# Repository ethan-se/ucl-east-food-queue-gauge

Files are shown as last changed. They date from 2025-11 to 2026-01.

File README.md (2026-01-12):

# Gauge & Grab

## Project Authors

This project was collaboratively developed by:

Ethan Taylor

Madina Diallo

Yussr Osman Kamil Bashir

🔗 GitHub Repository

The full source code, documentation, and project assets are available at:

👉 https://github.com/ethan-se/ucl-east-food-queue-gauge

## 📄 About This Repository
This repository contains the code, documentation, and supporting materials for the UCL East Food Queue Gauge project, developed as part of an academic group assignment.

**A Physical-[Digital](https://youtube.com/shorts/w2yIuAzpJI0?si=osPyPwr-uZf5rIN4) IoT System for Campus Dining Decisions**

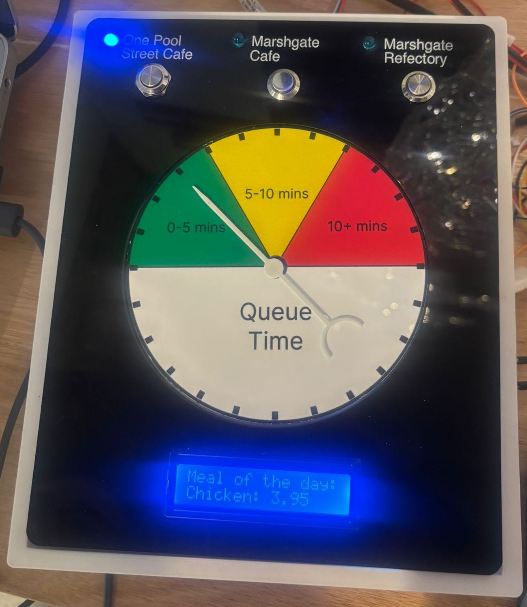
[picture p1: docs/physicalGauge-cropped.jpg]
Picture of Gauge and Grab physical device


---
## 1. Introduction & Rationale

University campus users frequently face uncertainty when deciding where to eat, particularly during peak hours. At UCL East, dining locations such as Pool Street Café, Marshgate Café, and Marshgate Canteen offer varied menus, daily specials, prices, and service speeds. However, users currently lack a quick, data-driven way to compare queue lengths and menu value in real time. This often leads to inefficiencies, long queues, and dissatisfaction.

Gauge & Grab was developed to address this everyday decision-making challenge through the design of a physical data device paired with a digital twin interface. The project explores how live (simulated) data, delivered through an Internet of Things (IoT) pipeline, can be visualised both analogue-physically and digitally augmented to support rapid, informed choices.

(Letsa, 2017)

The system allows users to instantly view:
- Estimated queue waiting time
- Daily specials and prices (Monday–Friday)
- Location-specific service characteristics

**Research Question:**  
*How can food-service data be presented in a fast, simple, and meaningful way to support informed decision-making on campus?*

---

## 2. Project Aims & Group Objectives

As a group, our objectives were to:
- Design and prototype a physical gauge that visualises live queue time immediately.
- Develop a digital twin and dashboard (Unity-based) that responds to the same live data feed.
- Use MQTT to demonstrate a real-time, end-to-end data pipeline.
- Enable users to make a dining decision within 5 seconds of interacting with the device.
- Show how analogue and digital systems can work together in a smart campus context.

---

## 3. Physical Device Design

### a. Aesthetic & Interaction Design

The physical gauge was designed to integrate naturally into the built environment at UCL East. Its form factor was inspired by devices commonly found near lecture rooms, such as thermostats or card readers, encouraging intuitive, brief interactions upon entering or exiting a space. 

(Aman, 2025)

The enclosure features:
- A laser-cut black acrylic front panel
- White etched typography using Helvetica, chosen for legibility and familiarity (Osborn, 2012)
- Magnetic mounting inspired by prior Connected Environments projects (e.g. SubRadar) (Low et al., 2024)
- A minimalist black-and-white aesthetic to complement existing campus infrastructure.
  


Each dining location is represented by:
- A dedicated button
- A corresponding LED indicator
- Clear etched labels on the front panel
  
  

This allows users to switch between locations with a single press, immediately updating the data displayed.

### b. Dial Graphic & Queue Representation

Queue time is visualised through a servo-driven pointer rotating across a semi-circular dial. The dial uses colour-coded zones:
- **Green (0–5 min)** – acceptable wait
- **Yellow (5–10 min)** – situational
- **Red (10+ min)** – undesirable

The dial graphic was designed in Figma and UV-printed onto acrylic. Due to manufacturing constraints, the final markers represent 75-second increments rather than the intended 60 seconds, an acknowledged limitation retained due to time constraints.



### c. Build Challenges

During final assembly, several physical issues emerged:
- The acrylic dial height exceeded the available servo shaft length.
- A 3D-printed spacer reduced torque accuracy.
- The final demonstration used a paper prototype dial to ensure functional clarity.

These challenges highlighted the importance of earlier physical prototyping and mechanical testing, particularly when combining laser-cut and 3D-printed components.

---

## 4. Code & Device Logic

### a. Arduino / NodeMCU Basis

The embedded code was built upon example implementations from the Open Gauges Project, retaining core libraries for:
- Wi-Fi connectivity
- MQTT publish/subscribe.
- Servo motor control

(Hudson-Smith, 2025)

Additional libraries were introduced to support:
- LCD screen output
- JSON parsing via Arduino Json



### b. MQTT Topic Switching

A key extension beyond the example code was dynamic topic switching, allowing one device to subscribe to three different MQTT topics, one per dining location.

An array of topics is stored, and button presses trigger:
- Unsubscription from the current topic
- Index update
- Subscription to the selected topic

This enables direct selection rather than cycling, improving usability and responsiveness.

### c. JSON Parsing & Data Handling

Incoming MQTT messages are structured as JSON objects. The device extracts:

**queue time** → mapped to servo position.

Due to time limitations, LCD display of daily specials and prices was not fully implemented in the final build, though code scaffolding demonstrates how this would be achieved safely within LCD character limits.

Queue values are constrained to a maximum range to prevent the servo exceeding the physical limits of the dial.



---

## 5. Data Design & Live MQTT System

### a. Research-Informed Dataset Design

Rather than using arbitrary values, we grounded our dataset in on-site observations and staff conversations at:
- Pool Street Café
- Marshgate Café
- Marshgate Canteen

Staff were asked about:
- Busy periods
- Average service speed
- Queue behaviour
- Menu rotation and daily specials

These insights informed our assumptions and data structure.



### b. Queue Time Model

Queue time was calculated using a simplified but transparent formula:

```
queue time = people_in_queue × service factor
```

Service factors differed by location based on observed service speed:
- **Pool Street Café**: ×1
- **Marshgate Café**: ×2
- **Marshgate Canteen**: ×3

This approach prioritised clarity and reproducibility over realism, appropriate for a demonstrative prototype.

(Eclipse Mosquitto, 2025)  
(Eclipse Foundation, 2024)



### c. MQTT Architecture

Data is published using the following topic hierarchy:



```
student/CASA0019/gauge&grab/
   ├── pool_street
   ├── marshgate_cafe
   └── marshgate_canteen
```

Each message includes:
- Location
- People in queue
- Queue time
- Daily special
- Price

Data is generated every 2 seconds via a Python script using Dabo-style publishing, simulating a live operational system.



### d. Verification

The pipeline was validated using MQTT Explorer, confirming:
- Correct topic structure
- Live updates across all locations
- Data consistency between publisher, physical device, and digital twin

(Python Software Foundation, 2025)  
(Schiffler, 2025)

### e. Data Summary

```
Real Questions at Cafés
        ↓
Draft dataset (menus, multipliers, queue ranges)
        ↓
Python generator → Live values every 2 seconds
        ↓
MQTT Publish → student/CASA0019/gauge&grab/<location>
        ↓
Physical Gauge Reads (Arduino)
        ↓
Digital Twin Reads (Unity AR)
```

---

## 6. Digital Twin (Unity)



## a.	Purpose of the Digital Twin

The digital twin complements our physical gauge by using augmented reality to visualise our dataset into an interactive digital gauge and dashboards for each location. The AR gauge receives live data from MQTT enabling users to pick their chosen location and view queue times and specials efficiently without having to be in proximity to the physical gauge. To ensure the user would be able to view the gauge in AR, the gauge was turned into a prefab in unity to ensure better control of the 3D model. In the scene with the XR Origin game object selected the tap to place script is added as a component in the inspector window with the digital gauge prefab selected as the game object to instantiate (workshop 6 Cetools.org, 2026). It is vital that the AR object (the digital gauge prefab) only lives inside the tap to place component and not as a game object in the scene hierarchy. An AR object UI bridge script is added as a component to the AR object prefab to enable the button to allow users to transition from the prefab to the dashboard.



The Dashboard expands on the gauge by turning historical and live data into digestible charts and tables that allow users to better plan and understand their canteen options (Workshop 3 Cetools.org, 2026). The dashboard exists as a child of the AR object. Each location's dashboard includes:
- Location name 
- A table that outlines the daily food specials for the week with a description of the food item, its price, caloric value, allergens, as well as an estimated serving time. This is incorporated in the dashboard in an image of each table. 
- A line graph that represents the locations weekly peak wait time. The graph enables users to plan and better understand wait time trends for the week. 
- Buttons were used to allow user to cycle from the AR object to the dashboard, A further three buttons were added to allow users to switch dashboards and return to the gauge. A dashboard navigation script ensures that buttons work smoothly and allow users switch between the dashboards.



### b. Unity & MQTT Integration

Our digital twin system transforms data received from MQTT into interactive and dynamic representations through our digital gauge and dashboards. An MQTT manager game object with an MQTT manager script as a component is added to the scene. The MQTT manager receives messages from MQTT ensuring connection the MQTT broker and subscription to our topics. The transformation of MQTT data into our interactive representations is done through two MQTT controller scripts.



For the digital gauge, an MQTT controller script was attached as a component of our AR object. This script locates the MQTT manager in the scene and receives data from its subscribed topics (workshop 6 Cetools.org, 2026). The MQTT controller script ensures that the gauge only displays data from the user's chosen location and ignores messages related to the other locations. Further the script changes the messages which it receives as Json text into C# strings and integers. The queue time is then calculated in the script as well as ensuring that the queue time displayed works with our gauge's range of rotation, start and end values, and gauge needles rotation.



As the dashboard exists as a child of the AR object the MQTT WeeklyChart Controller dashboard controller script is placed as a component inside the dashboard. The dashboard controller script receives data from the same MQTT manager however this script composites the data received over time to allow for it to be analysed. The controller tracks the busiest times for each location and visualises via a line chart for each location that displays weekly peak times.



### c. Limitations During Presentation

An issue faced was late integration of live data which was only successfully implemented the day of the presentation. This hindered our ability to assess whether the data was displayed and initialised correctly on the digital gauge and the line charts in the dashboard. This was further impacted as we faced issues with tap to place during the presentation that prevented the AR object from displaying as well as the button required to display the dashboard. 

We will ensure that issues like these are mitigated in the future by ensuring earlier end-to-end testing and ensuring that we document and film the tap to place function working prior to implementing the dashboard to ensure that a working demo was available for the presentation.

---

## 7. Individual Contributions

**Ethan Taylor**: Led physical device design, enclosure fabrication, dial graphics, servo integration, and Arduino logic.

**Madina Diallo**: Led project coordination, dataset design, MQTT architecture, Python data generation, system pipeline integration, documentation. 

**Yussr Osman Kamil Bashir**: Supported research, data structuring, testing, Unity dashboard development, and system validation.

---

## 8. Reflection

### a. What Worked Well
- Clear end-to-end data pipeline
- Shared MQTT feed driving physical + digital outputs.
- Intuitive, glanceable physical interface
- Strong alignment between research, data, and design

### b. Challenges and Limitations
- Simulated (dummy) data only.
- Simplified queue model
- Late physical and AR testing
- Mechanical constraints in final build

These were accepted to prioritise system architecture and real-time interaction.

---

## 9. Future Work

Future iterations could include:

- Address the 16-character LCD limitation by replacing it with a graphical OLED/TFT display or by using symbolic, colour-based indicators (e.g. LED bars or rings) to convey queue intensity. 

- A future improvement could also allow users to submit short, optional feedback digitally, and via an AR-based digital button after visiting a café, enabling us to compare lived experience with system estimates and continuously improve queue-time accuracy.

- Real queue detection via sensors or computer vision

- Integration with POS or menu management systems

- Predictive queue modelling using historical data.

- Personalisation (dietary needs, budget filters)

- Mobile companion app

- Staff-facing operational dashboard

Such developments would transform Gauge & Grab into a deployable smart-campus service (Letsa, 2017).

---

## 10. Conclusion

Gauge & Grab demonstrates how research-informed data, live MQTT messaging, and physical-digital visualisation can be combined into a coherent IoT system. 

We transformed simple café research, queue observations, menu requests, and staff Q&A into a structured dataset. We automated it with Python, broadcast it live through MQTT, and then connected both a physical gauge and an AR digital twin to the same data stream. This created a complete end-to-end IoT system built from real research, simulated data, and live messaging.

---

## References

- Aman, A. (2025) *Hand adjusting a smart thermostat on a white wall*. Vecteezy. Available at: https://www.vecteezy.com/photo/71521679-hand-adjusting-a-smart-thermostat-on-a-white-wall-increasing-the-room-temperature-for-comfort-and-energy-efficiency-the-digit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

- Cetools.org (2026a) *03: Dashboard and Real Time Data*. Available at: https://workshops.cetools.org/codelabs/casa0019-03-unity-dashboard/index.html

- Cetools.org (2026b) *06: Unity AR Physical to Digital*. Available at: https://workshops.cetools.org/codelabs/casa0019-06-unity-ar-pd/index.html

- Eclipse Foundation (2024) *paho.mqtt.python: Eclipse Paho MQTT Python client library*. Available at: https://github.com/eclipse-paho/paho.mqtt.python

- Eclipse Mosquitto (2025) *MQTT: Lightweight messaging protocol*. Available at: https://mosquitto.org/

- Hudson-Smith, A. (2025) *WindSpeedGauge.ino*. Open-Gauges. Available at: https://github.com/ucl-casa-ce/Open-Gauges/blob/main/Arduino/WindSpeedGauge/WindSpeedGauge.ino

- Letsa, L. (2017) 'Assessing the Effect of Waiting Times on Restaurant Service Delivery in the Ho Municipality, Ghana', *European Business & Management*, 3(6), p. 113. https://doi.org/10.11648/j.ebm.20170306.13

- Low, E. et al. (2024) *CASA0019: Sensor Data Visualisation – SubRadar*. Available at: https://github.com/rorschachwilpeng/casa0019/

- Osborn, J.R. (2012) 'Helvetica and the New York City Subway System', *Design and Culture*, 4(1), pp. 120–122. https://doi.org/10.2752/175470812X13176523285796

- Python Software Foundation (2025) *Python documentation*. Available at: https://www.python.org/doc/

- Schiffler, A. (2025) *How to use the Paho MQTT client in Python*. Cedalo Blog. Available at: https://cedalo.com/blog/configuring-paho-mqtt-python-client-with-examples/

- UCL Centre for Advanced Spatial Analysis (2025) *DaBo: Data in a Box repository*. Available at: https://github.com/ucl-casa-ce/dabo

---

## Acknowledgement

This report would like to acknowledge that AI was used to assist with support for coding in our project. AI was used to assist with coding for our physical gauge, digital twin, and data. AI was used in line with UCL assessment guidelines and was not used to generate ideas or text.

---

## License

This project was developed as part of CASA0019: Sensor Data Visualisation at UCL Centre for Advanced Spatial Analysis.

---

*For questions or collaboration opportunities, please contact the project team through the UCL CASA Connected Environments programme.*

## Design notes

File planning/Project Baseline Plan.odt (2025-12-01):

Project Baseline Plan

10-Day Product Development Timeline: Gauge & Grab System

Our Gauge & Grab System helps UCL East users pick the smartest meal option by instantly showing which location offers the fastest service and most appealing menu through a physical colour-coded gauge and a digital twin rich in contextual data.

🟢 Physical Gauge
🔵 Digital Twin
🟣 GitHub & Report

This timeline assumes the 10-day work period runs from Day 1 (December 2nd) to Day 10 (December 11th), with the final Showcase on December 12th.

Day | Date (Approx.) | Phase / Milestone | Key Tasks (Breakdown) | Assigned Team Lead | Necessary Tools/Systems
1 | Dec 2nd | Concept & Architecture (M1: System Spec Approved) | 1. Define final scope of 3 dining locations (Pool, Marshgate Cafe, Canteen). 2. Finalise Data Model Schema (EWT, Stock, Score, Weather). 3. Physical: Select Microcontroller (e.g., ESP32/Arduino) and components (stepper motor for needle, small TFT/E-Ink screen). 4. Digital: Choose Tech Stack (React/Next.js for Twin, Firebase/Firestore for Database). | MD (Data Lead) | Miro/Figma, Google Sheets, Arduino IDE, Visual Studio Code, Git/GitHub.
2 | Dec 3rd | Design & Mockups (M2: High-Fidelity Mockups Complete) | 1. Physical: Design 3D model for gauge housing (incorporate needle, screen, 3 buttons, colour zones). 2. Digital: Create high-fidelity UI/UX mockups for Digital Twin (Attractiveness Chart, Maps, Dialogue). 3. Data: Build EWT simulation logic (based on time of day, events, etc.) and create mock JSON feed. | ET (Design Lead) | Figma/Sketch, Fusion 360/Tinkercad, Python (for EWT simulation script).
3 | Dec 4th | Hardware Development I (M3: Core Physical Components Wired) | 1.Physical: 3D print initial casing prototype. 2. Physical: Wire and test microcontroller (MCU) with Wi-Fi/Cloud connection. 3. Integrate Stepper Motor control for Needle movement (0 to 180 degrees mapping EWT). | YOKB (Hardware Lead) | Arduino IDE/PlatformIO, Breadboard, Stepper Motor (with driver), Wires, 3D Printer (e.g., UCL workshop).
4 | Dec 5th | Data Pipeline Setup (M4: Data Mocking & DB Connection Ready) | 1. Data: Set up Firestore database (collections for locations, menu_items, EWT_history, weather). 2. Data: Write API endpoint (Node.js/Python) to serve mock EWT/Stock/Score data. 3. Physical: MCU pulls data from the API and successfully prints raw data to the Serial Monitor. | MD (Data Lead) | Firebase/Firestore, Node.js/Python, Postman (API Testing).
5 | Dec 6th | Digital Twin Development I (M5: Core Digital Twin UI Functional) | 1. Digital: Set up the main web application framework (React/Next.js) and GitHub Pages deployment environment. 2. Develop the main Dashboard layout, including placeholders for all 3 locations. 3. Integrate Chart.js/Recharts for Menu Attractiveness Chart (hardcoded data initially). | ET (Design Lead) | React/Tailwind CSS, VS Code, Git/GitHub.
6 | Dec 7th | Physical Integration I & Twin Data (M6: Physical Gauge EWT Live) | 1. Physical: Implement E-Ink/LED display showing the 'top item' status. 2. Physical: Map EWT values (from live data feed) to the Needle position (0-5 min Green, 5-10 min Yellow, 10+ min Red zones). 3. Digital: Connect Digital Twin to the Firestore/API data pipeline and display real-time EWT/Stock figures. | MD (Hardware) / ET (Digital) | Arduino C++, React/TypeScript, Firestore SDK.
7 | Dec 8th | Feature Development (M7: All Core Features Integrated) | 1. Digital: Develop interactive map visualization (simple SVG or Leaflet map showing queue length icons). 2. Digital: Build the Dialogue Feature placeholder (simple text input/output for personalized recommendations). 3. Data: Integrate a free Weather API to enrich the data feed (e.g., OpenWeatherMap mock-up). | YOKB (Data) / ET (Digital) | React Components, Weather API, Dialogue/LLM integration (if time allows, otherwise pre-canned responses).
8 | Dec 9th | End-to-End Testing & Refinement (M8: System passes E2E Test Scenarios) | 1. Testing: Run 10 predefined scenarios (e.g., "7:30 am, heavy rain, low stock at Pool St."). 2. Physical: Calibrate Needle precision and color mapping under all scenarios. 3. Digital: Cross-browser compatibility check and mobile responsiveness audit. | All Team Members (Joint) | User Testing Checklist, Browser Developer Tools.
9 | Dec 10th | Aesthetics & Showcase Prep (M9: Final Product Polish) | 1. Physical: Finalize casing aesthetics, paint, and button labels. Record demonstration videos/photos. 2. Digital: Apply final visual polish (Tailwind CSS theming, consistent color palette). 3. Documentation: Draft the core content for the GitHub README.md and the 2000-word Report structure (Introduction, Methodology, Results, Conclusion). | YOKB (Physical) / ET (Digital) | Figma/Design Assets, Video Camera, GitHub.
10 | Dec 11th | Finalization & Documentation (M10: Project Documentation Complete) | 1. Documentation: Write detailed personal contribution sections for the report. 2. Final code review and cleanup (add extensive comments). 3. Deploy final Digital Twin to GitHub Pages using the provided template (https://codepen.io/vsigno/pen/bGJKRYz). 4. Create the final project presentation slides/script. | All Team Members (Joint) | GitHub, Word Processor/LaTeX (for report).

Group Report (2000 Words, PDF of Readme)

The final 2000-word report, due January 12th, 2026, must follow a formal structure derived from the repository's README.md.

Section | Target Word Count | Key Content & Team Contribution
1. Introduction | 200 | Project Motivation (UCL East Wait Time Problem), Project Objectives (Gauge & Grab functionality), Scope, and Report Structure.
2. Design & Architecture | 400 | 2.1 Physical Gauge: Hardware selection (MCU, Motor, Display), Casing Design Rationale (MD). 2.2 Digital Twin: Tech Stack Choice (React, Tailwind), UI/UX Rationale (ET). 2.3 System Architecture: Data flow diagram (Physical <-> Firestore <-> Digital Twin) (YOKB).
3. Methodology & Development | 500 | 3.1 Data Pipeline: Detailed EWT calculation logic, Data Feeds (Weather, Stock), and Database Structure 3.2 Physical Prototype Implementation: Code logic for needle movement, color-coding mapping, and button interaction. 3.3 Digital Twin Implementation: Key features (Attractiveness Chart, Maps), Dialogue feature placeholder (ET).
4. Testing & Validation | 300 | Results of End-to-End Scenario Testing, Calibration of EWT to Color Zones, User Feedback/Iteration Process.
5. Individual Contributions | 400 | X: 3D printing, circuit design, MCU coding, physical assembly. X: Digital Twin UI/UX, Front-end development, visual polish. X: Data modeling, EWT algorithm, API development, Firestore management.
6. Conclusion & Future Work | 200 | Summary of success against objectives, challenges encountered (e.g., motor precision, real-time data), and future enhancements (e.g., ML-driven EWT, haptic feedback).

Digital Twin Showcase (December 12th)

The digital component must be hosted on GitHub Pages using the provided template. The focus should be on visualisation and interactivity.

1. Dashboard: Display the color-coded status for all three locations simultaneously, with the main Gauge graphic dominating the screen.
2. Attractiveness Chart: A responsive chart showing Menu Attractiveness (Y-axis) vs. EWT (X-axis) for each location, allowing users to see the trade-off.
3. Real-time Data: Show livestock levels and estimated queue length (as a number of people) updated via the Firestore connection.
4. Dialogue Feature: A simple chat window demonstrating personalized advice, e.g., "Given your history of ordering vegetarian, Pool Street has a Quinoa Salad special today. The EWT is 4 minutes."

Daily Breakdown of Tasks & Milestones

### Day 1: Kickoff & Planning

- Assign roles and responsibilities.
- Sketch gauge concepts
- Wireframe digital twin in Figma
- Define data feeds

### Day 2: Design Phase

- CAD design of gauge in Fusion360
- UI design in Figma/PenPot
- Setup MQTT & REST API feeds

### Day 3: Build Phase Begins

- 3D print gauge housing
- Develop Unity3D twin base
- Integrate data feeds

### Day 4: Hardware & Software Expansion

- Assemble electronics: LED, motor, E-Ink
- Build menu & queue visuals
- Add weather API + menu stock logic

### Day 5: Feature Integration

- Install needle/dial mechanism
- Add personalized recommendation engine

### Day 6: Testing Phase

- Test physical gauge display
- Test digital twin UI

### Day 7: Final Feature Additions

- Integrate gauge with live data feed
- Add E-Ink/LED menu display
- Add real-time map & charts

### Day 8: System Integration Test

- Full system test and debugging (All).

### Day 9: Showcase Prep

- Record demo video and take photos (All).
- Compress media using HandBrake/Squoosh
- Write GitHub leaflet using CodePen template

### Day 10: Final Presentation

- Present Gauge & Grab system at UCL East.
- Upload to GitHub Pages.
- Begin drafting 2000-word report for January 12.

## Tools & Platforms Used

- Design: Fusion360, Figma, PenPot, Blender
- Development: Unity3D, ARFoundation, VSCode
- Data Feeds: MQTT (CE Server), REST API
- Assets: Sketchfab (3D), Freesound API (audio)
- Compression: HandBrake, Squoosh
- Documentation: GitHub, CodePen template

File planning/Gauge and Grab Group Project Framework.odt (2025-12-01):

## Gauge and Grab Group Project

## Brainstorming & Requirements Gathering

### 1. Data Feed & Context

The project focuses on UCL East dining locations: Pool Street Café, Marshgate Café, and Marshgate Canteen.

- Targeted Audience:
- Students
- Staff
- Visitors.
- Key Data Inputs:
- Queue length/time
- Menu availability (stock levels, daily specials)
- Foot traffic patterns
- Peak hours
- Critical Values to Generate:
- Predictive Plate Gauge Status
- Digital Twin Detail

### 2. Device Requirements (Physical & Digital)

Component | Functionality | Key Features
Physical Gauge | Decision-Making Aid | Color-Coded EWT: Green (0-5 min), Yellow/Amber (5-10 min), Red (10+ min). Needle Position: Shows estimated wait time. Menu Info: Rotating digital display/icons for top items. Augmented Twin Link: QR Code/NFC to load the Digital Twin
Augmented Digital Twin | Context & Deep Dive | Interactive Map: Real-time occupancy, queue lengths, available seating… Menu Details: Full menu, nutritional, allergen information Personalised Recommendations: Based on user preferences/historical data Event Integration: Special events, promotions

### 3. Data Flow and Tech Stack (Back-end)

- Data Acquisition: Use existing data (API) and/or generated dummy data for: Queue Length (people), Avg Service Speed (min/person), Stock % (e.g., popular items), Prep Time (min), Popularity/Attractiveness Score
- Data Processing: Calculate Estimated Wait Time (EWT) (Queue Length times Avg Service Speed)¹⁹. Apply Decision Logic to generate PCPS (combining EWT, Menu Attractiveness, and Event Impact)
- Data Transmission: MQTT for real-time Gauge updates and REST API for Digital Twin data requests
- Required Tools: VSCode , Unity3D , Digital Twin, Blender or Fusion360 for 3D assets, Figma or PenPot for collaborative design.

### 4.Scope and Roadmap

The project's scope is to deliver a fully functional, integrated physical data device and augmented digital twin, focused on dining decision support at UCL East.

Phase 1: Planning & Data

- Design: Finalize physical device sketch and Digital Twin UI/UX (Figma/PenPot)
- Data Setup: Create realistic dummy datasets for all three locations, covering Queue, EWT, and Menu Attractiveness
- Server: Set up CE MQTT Server and a basic REST API endpoint

Phase 2: Physical Prototype Development

- Hardware: Source microcontroller (e.g., ESP32), servo/stepper motor for the dial/needle, and colour LEDs/display
- Firmware: Develop code to connect to MQTT, subscribe to PCPS data, and actuate the needle/LEDs based on the data feed
- Enclosure: Design and 3D print/fabricate the device enclosure (Blender/Fusion360)
- Documentation: Start gathering images/videos of the physical prototype.

### Phase 3: Digital Twin Development

- Twin Structure: Develop the AR/Web-based Digital Twin application (Unity3D/AR Foundation)
- Data Integration: Connect the app to the REST API to fetch detailed queue, menu, and occupancy data
- Augmentation: Implement the QR Code/Image Target functionality (Entry Point). Implement virtual pointers, charts, and interactive elements (Augmentation).
- Final Touches: Implement the digital information leaflet using the provided CodePen template.

### Phase 4: Integration, Testing & Final Report

- System Integration: Ensure seamless, two-way link between the physical Gauge (MQTT) and the Digital Twin (REST API/QR Code)
- Testing: Test the system under various scenarios (e.g., peak lunch rush, low stock situation)
- Documentation: Complete the GitHub repository Readme (PDF Report)
- Prepare final videos and APK.

### 5.Project Plan & Timeline (Detailed Breakdown)

The timeline is structured for a submission date of Thursday, December 12, 2025, for the Data Device, and Monday, January 12, 2026, for the Group Report.

Task Category | Task Name | Est. Time (Days) | Deadline | Deliverable
I. Planning | Define Final PCPS Logic & Data Model | 2 | End of Week 1 | PCPS Algorithm Document
| Sketch & Finalize Physical/Digital Design | 3 | End of Week 1
| Set up GitHub Repo & Documentation Template | 1 | End of Week 1 | Repository Initialized
II. Physical Device | Source Components & Test Basic Electronics | 3 | End of Week 2 | Components List & Basic Blink/Servo Test
| Develop MQTT Subscriber Firmware (EWT) | 4 | End of Week 3 | Code: MQTT Connection & Needle Actuation
| Design 3D Model of Enclosure (Fusion360) | 3 | End of Week 3 | STL/CAD Files
| Fabricate & Assemble Physical Prototype | 5 | End of Week 4 | Physical Data Device V1.0
III. Digital Twin | Set up Unity/ARFoundation Project | 2 | End of Week 5 | Empty AR Project
| Develop REST API Client & Data Visualization | 4 | End of Week 6 | Code: Data Fetch & Interactive Charts
| Implement AR/Image Target Functionality (QR Code) | 3 | End of Week 7 | AR Scene with Digital Twin Overlay
| Add Full Menu, Reviews, and Recommendation Logic | 4 | End of Week 8 | Augmented Digital Twin V1.0 (APK)
IV. Integration | Link Gauge and Twin (Test Data Sync) | 2 | End of Week 9 | Functional, Integrated System Demo
| Final Polish & High-Quality Photo/Video Shoot | 2 | End of Week 9 | Showcase Media
V. Assessment | Final Device Submission | 1 | Dec 12, 2025 | Physical Device, APK, Video/Images
| Draft Report (Sections 1-3) | 3 | End of Week 10 | Draft Narrative & Methodology
| Draft Report (Sections 4-6) & Edit/Proofread | 4 | Mid-Jan 2026 | Final PDF/Readme Report
| Final Report Submission | 1 | Jan 12, 2026 | Group Report PDF

6.Product Features and Document

- Device Name: Predictive Gauge & Grab
- Purpose and Functionalities

The Predictive Gauge & Grab system is a smart meal decision-making aid for the UCL East campus⁴³.

- Functionality: To minimize user, wait time and frustration by directing them to the quickest dining option that meets their needs (queue vs. food attractiveness).
- The Gauge (Physical): Provides a quick, color-coded status (Green/Yellow/Red) for the predicted best option, primarily driven by the Estimated Wait Time (EWT).
- The Digital Twin (Augmented): Provides the context and reasoning, detailing queue length, service speed, menu stock levels, and daily specials for all locations.
- Displayed Data Feed
- Physical Gauge Visualisation: The Gauge displays the Predictive Plate Gauge Status (PCPS), an abstraction of the core data for a single, recommended location.
- Visual Element: Needle/Dial Graphic.
- Data Representation: Estimated Wait Time (EWT) mapped to colour zones.
  - Green Zone: 0-5 minutes ("Go Low/No Wait")
  - Yellow/Amber Zone: 5-10 minutes ("Slow/Moderate Wait")
  - Red Zone: 10+ minutes ("Stop/Long Wait")
- Additional Element: Small, rotating E-Ink display or LED matrix for the top item (e.g., "Roast Dinner") or status ("See Digital Twin")
- Digital Twin Augmentation: The Augmented Twin offers detailed, raw, and interpreted data for all locations.
- Menu Attractiveness Chart: Score (1-5) vs. EWT, showing the trade-off decision.
- Real-time Maps: Interactive floor plans showing queue lengths (e.g., number of people) and seating availability.
- Stock Levels: Percentage of popular items remaining (e.g., "Croissant: 30% - Almost sold out").
- Dialogue Feature: Personalised recommendations based on user history or current specials.

### 4. Digital Information Leaflet (GitHub Main Page)

The GitHub main page will be structured as the digital information leaflet using the required template.

- Repository Link: Github
- Main Page (Readme.md): Will follow the template structure (https://codepen.io/vsigno/pen/bGJKRYz) and include:
  - Device Name: Gauge and Grab System
  - Purpose and Functionalities (as above)
  - Screenshots/Short Gifs of the Physical Gauge and Digital Twin in action.
  - A breakdown of the PCPS logic (EWT, Menu Attractiveness, Event Factor).
  - Link to the final Group Report (PDF).

Task Breakdown (Smallest Tasks)

### 1. Data & Server (Micro-Tasks)

- Data Creation: Populate CSV/JSON with realistic dummy data for 3 locations, including all required fields (Queue, EWT, Stock, Prep Time, Popularity)
- MQTT Setup: Install/configure CE MQTT Server instance. Define MQTT topics (e.g., casa/pcps/marshgate_canteen).
- API Development: Create simple Python/Node.js API to serve the detailed menu/occupancy data via REST API⁶¹.

### 2. Physical Device (Micro-Tasks)

- Needle Control: Calibrate servo/stepper motor to sweep the gauge range (0-15+ min) accurately.
- LED/Colour Coding: Write firmware logic to set LED colours (Green/Yellow/Red) based on the received MQTT PCPS value.
- Menu Display: Integrate E-Ink/LED screen and write code to pull the 'Top Item' string from a separate MQTT topic or embedded data feed.
- QR Code: Generate high-resolution QR code linking to the Digital Twin URL and physically affix it to the device.

### 3. Digital Twin (Micro-Tasks)

- Asset Creation: Model simple 3D assets for the dining locations (Marshgate Canteen, etc.) or use assets from Sketchfab.
- AR Target: Set up the image target recognition for the QR code/device image to trigger the AR overlay (Augmented Twin).
- UI/UX: Design and implement the interactive chart visualisation for the trade-off decision (Queue vs. Attractiveness).
- Full Menu View: Program the display of the full, detailed menu, including allergen and nutritional data fetched from the REST API

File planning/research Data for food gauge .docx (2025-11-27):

Marshgate café

-Monday is the busiest day staff was unable to specify what time as it was dependent on the students’ timetable

-Most popular menu items are flat white, chicken bagel, pain au chocolate

One pool st café

-Monday and Tuesday are the busiest days, and Friday is the slowest day

-busiest times are 9am and 11am

-Queue wait times are often due to the type of item the costumer purchases

If it is a ready-made scan and go item the line moves very quick however if all the costumers are wanting coffees or food items that need to be heated up the queue time goes up significantly. It takes the barista around 30 seconds to make one coffee.

-the queue often slows down when a big order is placed such as group orders

-Most popular items are Latte and Iced Americano

Canteen

-Thursdays and Fridays are quite busy due to the availibity of fish and chips that day.

-Peak busy times are 8-11 for breakfast and 11-2 for lunch

-Queue wait times and busy days are dependent of the students timetables

-Most popular items are Fish , chips , and chicken dishes ( burger , wings , strips , and leg)

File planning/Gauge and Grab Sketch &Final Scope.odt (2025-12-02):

As disscussed, we need to amend and update the below based on the followings:

The updated UCL East dining gauge would feature:

• Three location buttons at the top (Pool Street Cafe, Marshgate Cafe, Marshgate Canteen)

• A circular clock-style gauge in the centre with color-coded sections:

◦ Green section (0-5 minutes)

◦ Amber section (5-10 minutes)

◦ Red section (10+ minutes)

• A moving needle pointing to the current wait time

• Below the gauge on the screen, details for the selected location through relevant button (eg : Pool Street Cafe):

◦ Today's special: Meal Deal(sandwich,Drink,Snakck) - £3.95

◦ Current wait time: 7 minutes (needle in amber zone)

• A QR code in the corner for accessing the digital twin with more information

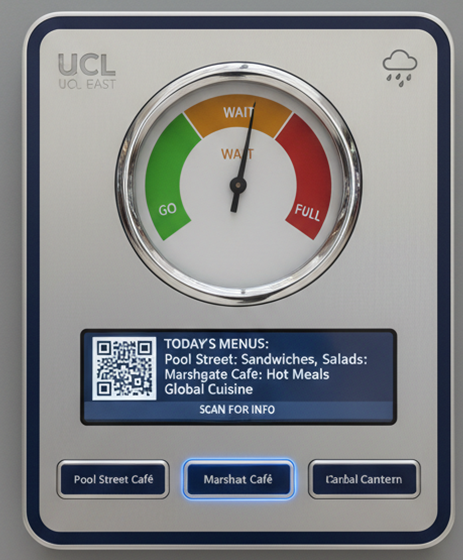
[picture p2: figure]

Green: (0-5 minutes) Low Wait.

Yellow/Amber: (5-10 minutes) Moderate Wait.

Red: (10+ minutes) Long Wait

1. Relevant Menu Information

Special of the Day: Highlight the daily special or featured item. This encourages users to try new offerings and can help manage inventory.

Wait Times: Estimated time to receive an order can heavily influence a user's decision.

Price Range: A general indication of the affordability £££ helps users on a budget.

- Pool Street Café:

Coffee Specials: Highlight any unique or seasonal coffee drinks.

Pastries Available: Indicate the selection of fresh pastries.

Quick Bites: Sandwiches, salads, or other items that can be prepared quickly. Promote any bundled deals on snacks and drinks.

- Marshgate Café:

Vegan/Vegetarian Options: Clearly indicate the availability of plant-based choices.

Healthy Options: Highlight items known for their nutritional value (e.g., salads, smoothies).

Snack Deals: Promote any bundled deals on snacks and drinks.

- Marshgate Canteen:

Main Course Options: Display the main dishes available for lunch or dinner.

Dietary Information: Note any gluten-free, halal, or other dietary options.

Full Menu Link: Provide a quick link (via QR code or NFC tag) to the complete menu on the

digital twin.

Component | Functionality | Key Features
Physical Gauge | Decision-Making Aid | Color-Coded EWT: Green (0-5 min), Amber (5-10 min), Red (10+ min). Needle Position: Shows estimated wait time. Menu Info: Rotating digital display/icons for top items. Augmented Twin Link: QR Code/ to load info template and the Digital Twin
Augmented Digital Twin | Context & Deep Dive | Interactive Map: Real-time occupancy, queue lengths, available seating,EST for the other items on the menu Menu Details: Full menu, nutritional, allergen information, calories, price, stock level/availability Personalised Recommendations: Based on user preferences/historical data,user experience (multiple choice questions) Event Integration: Special events, promotions, timetables, footfall etc…

Gauge and Grab System

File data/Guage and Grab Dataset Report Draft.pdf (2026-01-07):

## CASA0019: Sensor Data Visualisation 25/26 Guage and Grab Final Group Report

Group Members/Authors: Ethan Taylor; Madina Diallo; Yussr Osman Kamil Bashir Link to the GitHub repository: https://github.com/ethan-se/ucl-east-food-queue-gauge

Rationale
Research Background & Project

University campus users regularly face uncertainty when choosing where to eat, especially during peak hours.
At UCL East, three key dining locations: Pool Street Café, Marshgate Café, and Marshgate Refectory, offer multiple menu options, daily specials, and a wide range of prices. However, there is currently no quick, data-driven way for students and staff to compare these choices in real time. This often leads to long queues, inefficient decision-making, and dissatisfaction & Grab was developed in response to this gap.
Our project investigates how a physical analogue device, paired with a digital-twin interface, can support users in making faster and smarter meal decisions. The concept allows users to immediately view:
•The menu options for each location (Mon–Fri)
•Daily specials and prices to help compare cost and value
•An estimated live queue-waiting time, generated through dummy / simulated data feeds via MQTT

By presenting this information through both a physical gauge (at-a-glance decision aid) and an augmented digital dashboard (expanded detail), the project aimed to reduce uncertainty and improve the everyday experience of choosing where to eat on campus.
Why We Chose This Problem?
We focused on this topic because it represents an everyday challenge that affects large numbers of people at UCL East. Our decision to help users make informed choices is grounded in three key observations:
•Time and convenience are critical factors in campus decision-making.
•Data is available but not accessible, and users cannot currently visualise queue time or menu differences instantly.
•A single, centralised display could reduce frustration, spread footfall more evenly, and improve overall campus flow.

In short, our research is framed around the question:
How can we present food-service data in a fast, simple, and meaningful way that empowers users to make informed decisions?

Data

Data Feeds Chosen
We selected three core data feeds for our prototype:
These data feeds are generated as structured dummy datasets, published through MQTT to simulate a live operational system.
Group Aim
As a group, our aim was to:
- Build a physical gauge that visualises queue time + menu status
- Create a digital twin’s dashboard with expanded details and live data response
- Enable users to make a choice within 5 seconds of looking at the device
- Demonstrate how analogue and digital systems can work together for campus decision support
How We Created Our Dataset & Live MQTT System
(From market research → dataset design → live MQTT → device integration)

### 1. Research & Data Collection at the 3 Locations

We began by visiting each of our chosen UCL East food locations:
- Pool Street Café
- Marshgate Café
- Marshgate Canteen

Questions Asked to Staff:
Category | Example Questions
Busy Period | What days and time are the busiest?
Service Speed | “How long does it normally take to serve one person on average ?”
Menu & Daily Specials | “Do you have weekly rotations or a fixed special per day?”
Bottlenecks | “What slows service? Preparation? Payment? Equipment?”
Queue Behaviour | “At busy times, how many people are usually waiting and how do staff cope ?”

These answers formed the foundation of our dataset.
Daily Specials (Drafted from menus & staff responses

### 2. Building the Dummy Dataset (Structured from Research)

We then drafted a dataset that simulated real conditions but remained controlled and predictable.

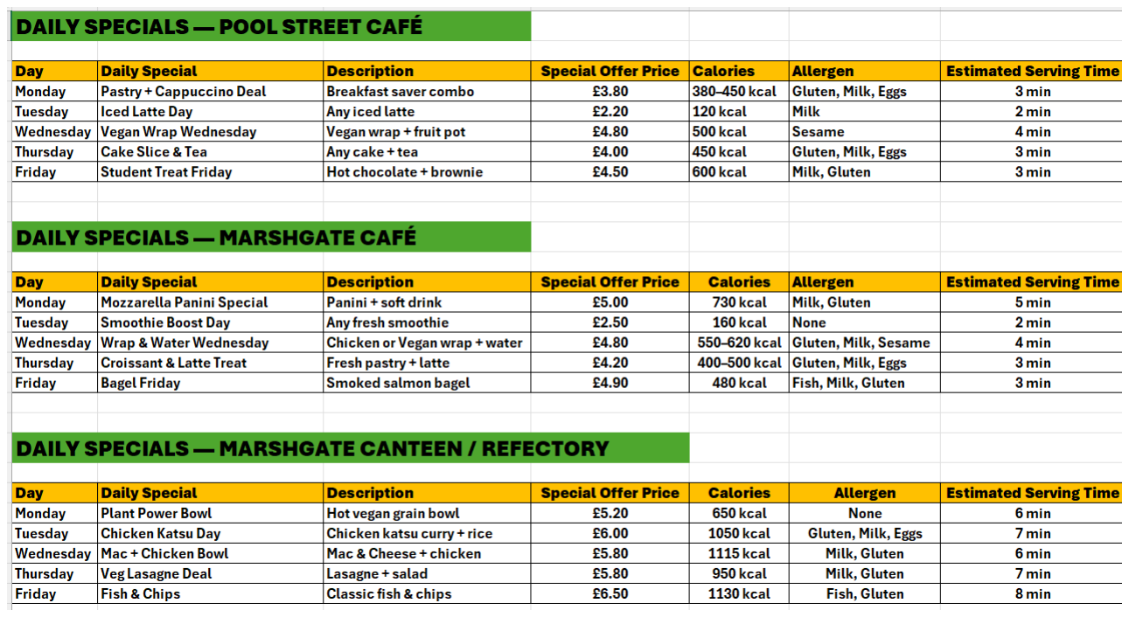
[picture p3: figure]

Data Feed Type | Purpose | Output Example
Menu Data (Mon–Fri) | Shows available items without searching online | “Chicken Wrap – £4.50”
Daily Special & Prices | Encourages discovery + better value choices | “Wednesday: Mac &Chicken Bowl – £5.80”
Live Queue Time Estimate (MQTT Dummy Data) | Helps users choose based on waiting duration | “Approx. 7 minutes wait”

Insights We Used
Location | Avg. Queue | Speed per person | Multiplier
Pool Street Café | Small queue | Fast | ×1
Marshgate Café | Medium | Normal | ×2
Marshgate Canteen | Larger queue | Slowest | ×3
Queue Time Formula
This formula became our standard:
queue_time = number_of_people × service_factor
Final Data Structure (JSON format used later for MQTT) {
"location": "pool_street",
"people_in_queue": 6,
"service_factor": 1,
"queue_time": 6,
"daily_special": "Cake Slice & Tea", "price": "6.50"
}

### 3. Designing Topics for MQTT (Data Architecture)

To publish data properly, we needed a logical topic hierarchy to separate each location:
student/
CASA0019/
gauge&grab/
pool_street
marshgate_cafe
marshgate_canteen

Each device subscribes only to the location it needs.

### 4. Creating Live Data in Python (DaBo Publisher Script)

main.py
import time, random, json
from mqtt_publisher import MQTTClient

# MQTT connection

client = MQTTClient("mqtt.cetools.org", 1884, "student", "ce2024")

# Locations + service multipliers

locations = {
"pool_street": 1,
"marshgate_cafe": 2,
"marshgate_canteen": 3
}

# Daily specials

specials = {
"pool_street": ("Vegan Wrap & Fruit Pot", "4.80"), "marshgate_cafe": ("Panini Soft Drink", "5.00"), "marshgate_canteen": ("Fish & Chips", "6.50") }

while True:
for location, factor in locations.items():
people = random.randint(1, 20)
queue_time = people * factor # formula from research

data = {
"location": location,
"people_in_queue": people,
"queue_time": queue_time,
"daily_special": specials[location][0], "price": specials[location][1]
}

topic = f"student/CASA0019/gauge&grab/{location}" client.publish(topic, json.dumps(data), retain=True) print("Published → ", topic, data)

time.sleep(2)
Result: Every 2 seconds, live data gets published to all three topics.

### 5. Data Arrives in MQTT Explorer (Verification Step)

To confirm everything works:
1. Open MQTT Explorer
2. Add broker:
3. Host: mqtt.cetools.org
4. Port: 1884
5. Username: student
6. Password: ce2024
7. Subscribe to:
8. student/CASA0019/gauge&grab/#

live queue data updating in real time.

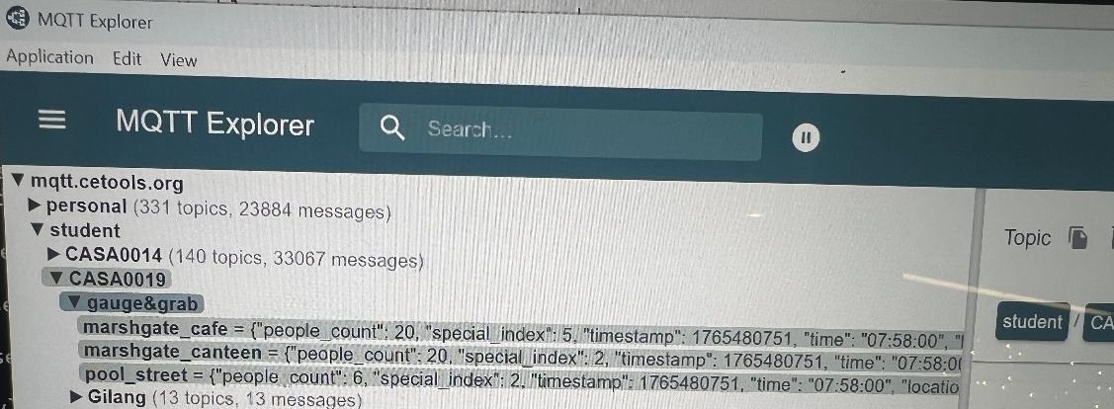
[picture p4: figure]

### 6. Subscribing with the Physical Gauge (Arduino)

Arduino Pseudocode Subscribe Logic client.subscribe("student/CASA0019/gauge&grab/pool_street");

if(messageArrived){
queue_time = payload["queue_time"]; moveGaugeNeedle(queue_time); lcd.print(payload["daily_special"]);
}
The gauge needle + LCD now update in real time.

### 7. Unity Digital Twin Subscription (C# Script)

mqttManager.cs
client.Subscribe("student/CASA0019/gauge&grab/#");

void OnMessageArrived(string topic, string message) { var data = JsonUtility.FromJson<GaugeData>(message); dashboard.Update(data.queue_time); graph.AddPoint(data.queue_time);
}
The AR dashboard + graphs update based on the same live feed.

### 8. Summary of the System Pipeline

Real Questions at Cafés
↓
Draft dataset (menus, multipliers, queue ranges) ↓
Python generator → Live values every 2 seconds
↓
MQTT Publish → student/CASA0019/gauge&grab/<location> ↓
Physical Gauge Reads (Arduino)
↓
Digital Twin Reads (Unity AR)

Group Reflection

Limitations
Despite its effectiveness as a prototype, the system has several limitations:
- The dataset is simulated and does not reflect real-time operational data
- Queue sizes are randomly generated rather than sensor-derived
- Service speed is simplified into fixed multipliers
- User-specific factors (dietary needs, budget constraints) are not currently included
- Long-term data persistence and historical storage were not implemented These limitations were accepted to prioritise system architecture, interaction design, and real-time data flow within the project scope.
Future Work
Future development could address these limitations by:
- Integrating real sensors (e.g. people counters or computer vision) for live queue detection
- Connecting to real menu management or point-of-sale systems
- Applying machine learning to predict queue times based on historical trends
- Adding personalisation features such as dietary preferences or budget filters
- Developing a mobile application to complement the physical gauge

- Providing a staff-facing dashboard for operational decision-making
These enhancements would transform Gauge & Grab from a demonstrative prototype into a fully deployable smart-campus service.
“A future improvement would allow users to submit short, optional feedback after visiting a café, enabling us to compare lived experience with system estimates and continuously improve queue-time accuracy.”
“The project was structured with a dedicated virtual environment separated from the application code to ensure reproducibility, clean dependency management, and ease of deployment. All application logic, configuration, and documentation were contained within a single project directory suitable for version control.”

References:
- Eclipse Foundation (2024) paho.mqtt.python: Eclipse Paho MQTT Python client library. Available at: https://github.com/eclipse-paho/paho.mqtt.python (https://github.com/eclipse-paho/paho.mqtt.python)
- Eclipse Mosquitto (2025) MQTT: lightweight messaging protocol. Available at: https://mosquitto.org/
- Python Software Foundation (2025) Python documentation. Available at: https://www.python.org/doc/
- Schiffler, A. (2025) How to use the Paho MQTT client in Python with examples. Cedalo Blog. Available at: https://cedalo.com/blog/configuring-paho-mqtt-python-client-with-examples/ (https://cedalo.com/blog/configuring-paho-mqtt-python-client-with-examples/)
- UCL Centre for Advanced Spatial Analysis (2025) DaBo: Data in a Box. Available at: https://github.com/ucl-casa-ce/dabo

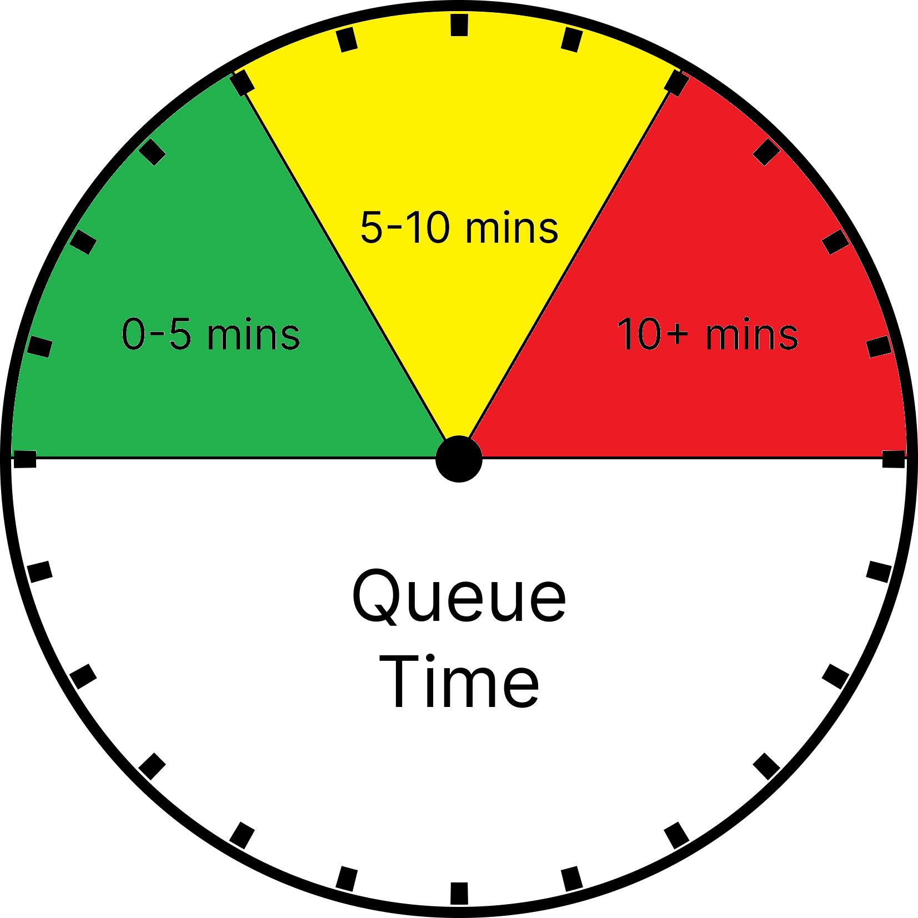
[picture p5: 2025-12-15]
digitalTwin/Assets/gauge-glass-anim (2).fbm/dialDesignColour-2.png

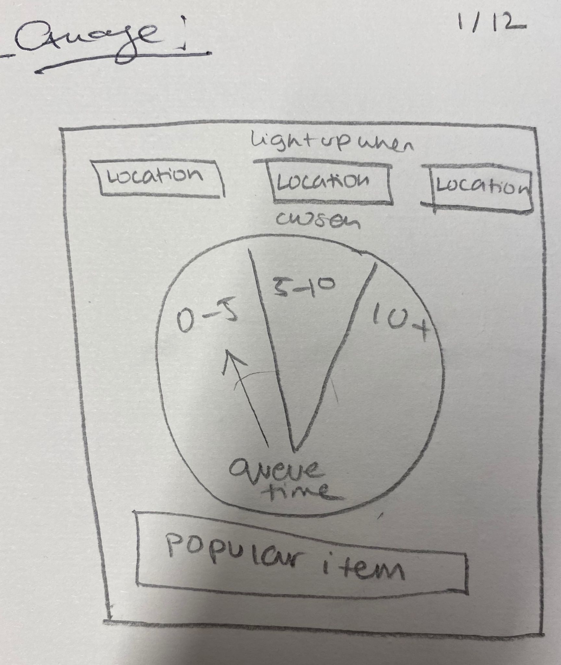
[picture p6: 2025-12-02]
docs/concept-sketch-gauge.jpeg

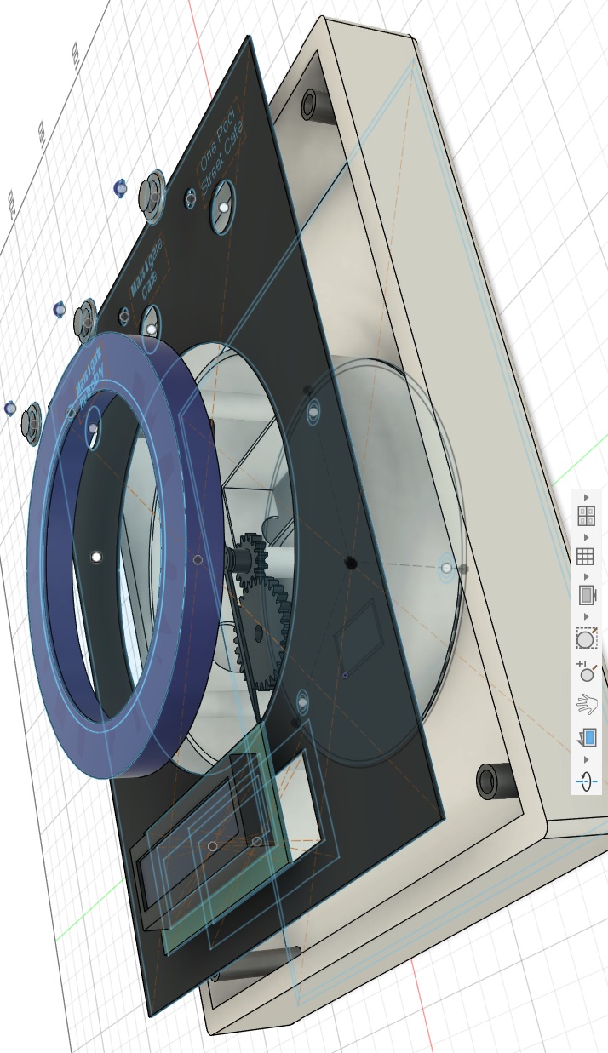
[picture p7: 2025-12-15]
docs/design-screenshot-0.jpg

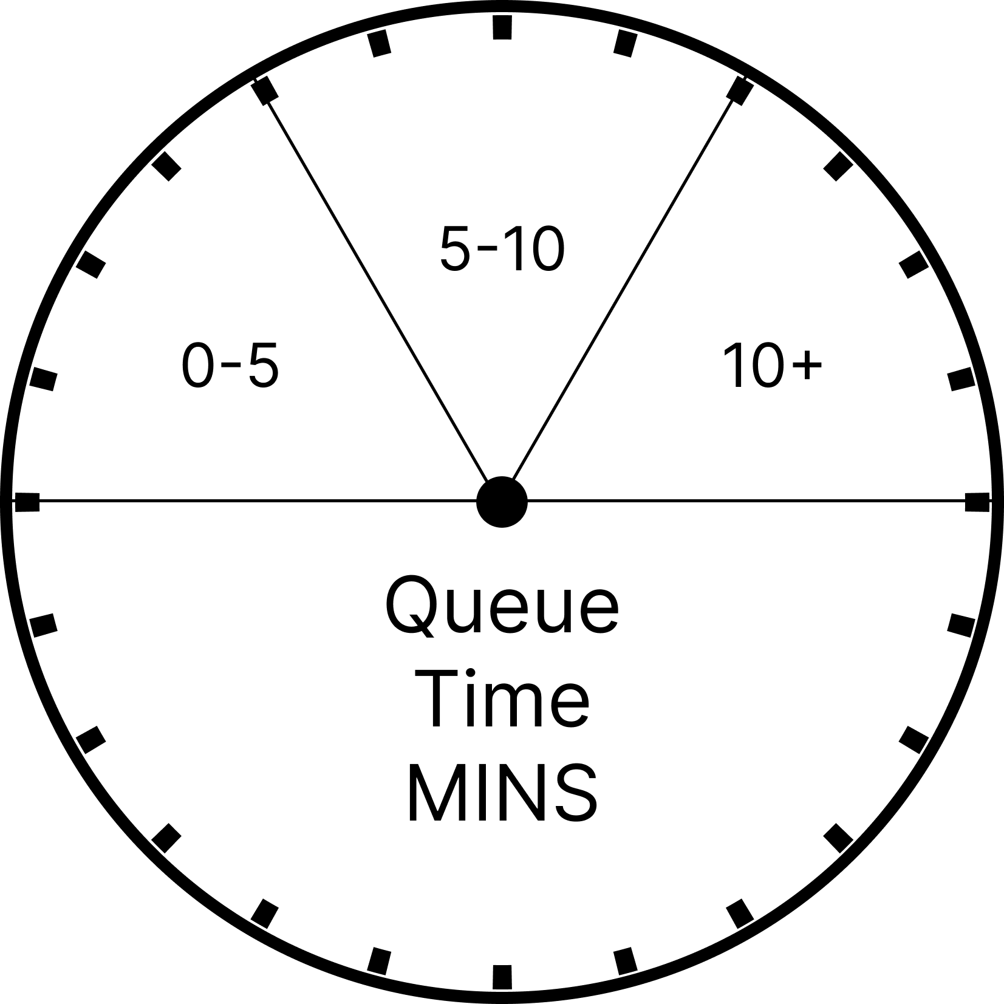
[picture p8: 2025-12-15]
physicalDevice/uvPrint/dialDesignMono.png

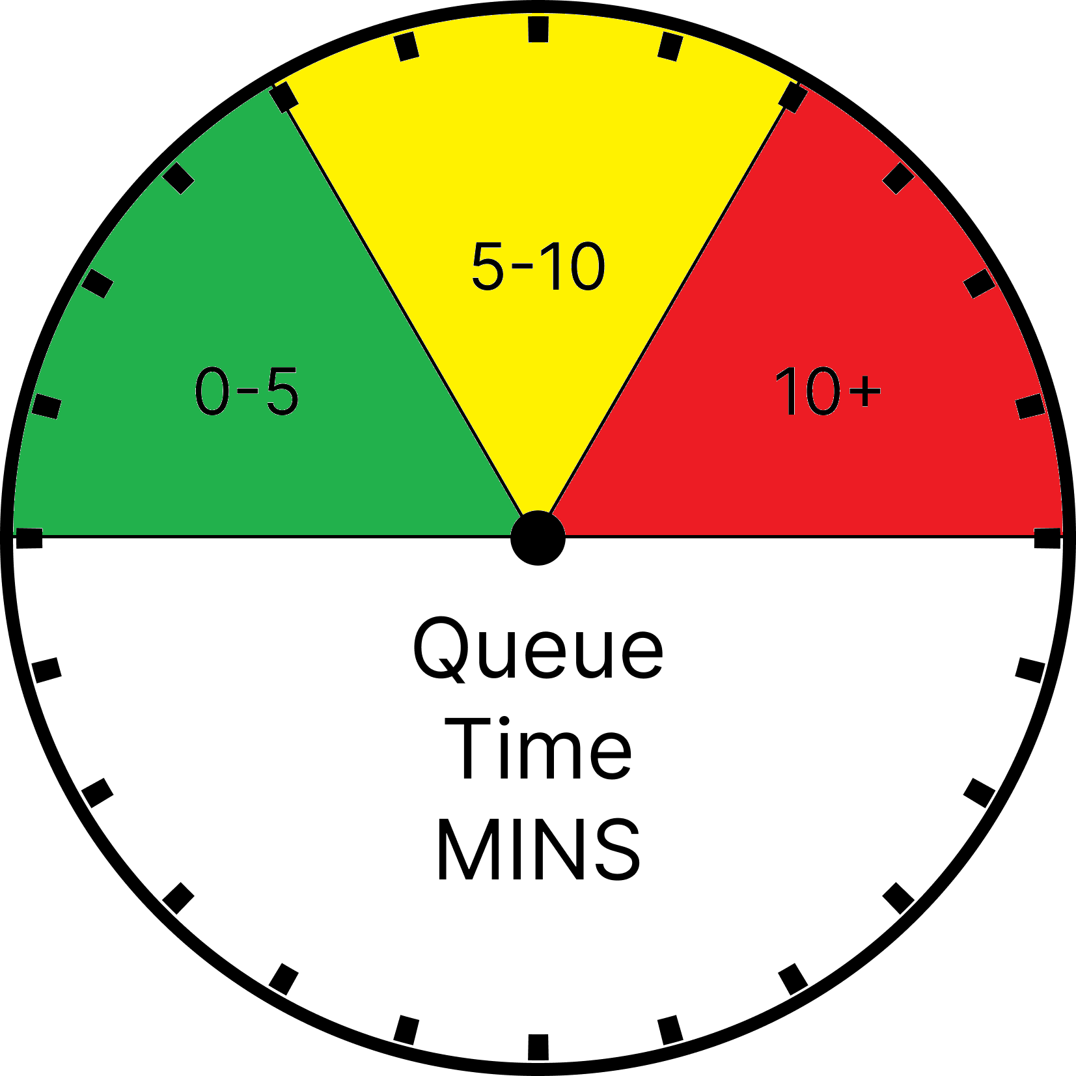
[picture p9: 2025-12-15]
physicalDevice/uvPrint/dialDesignColour.png

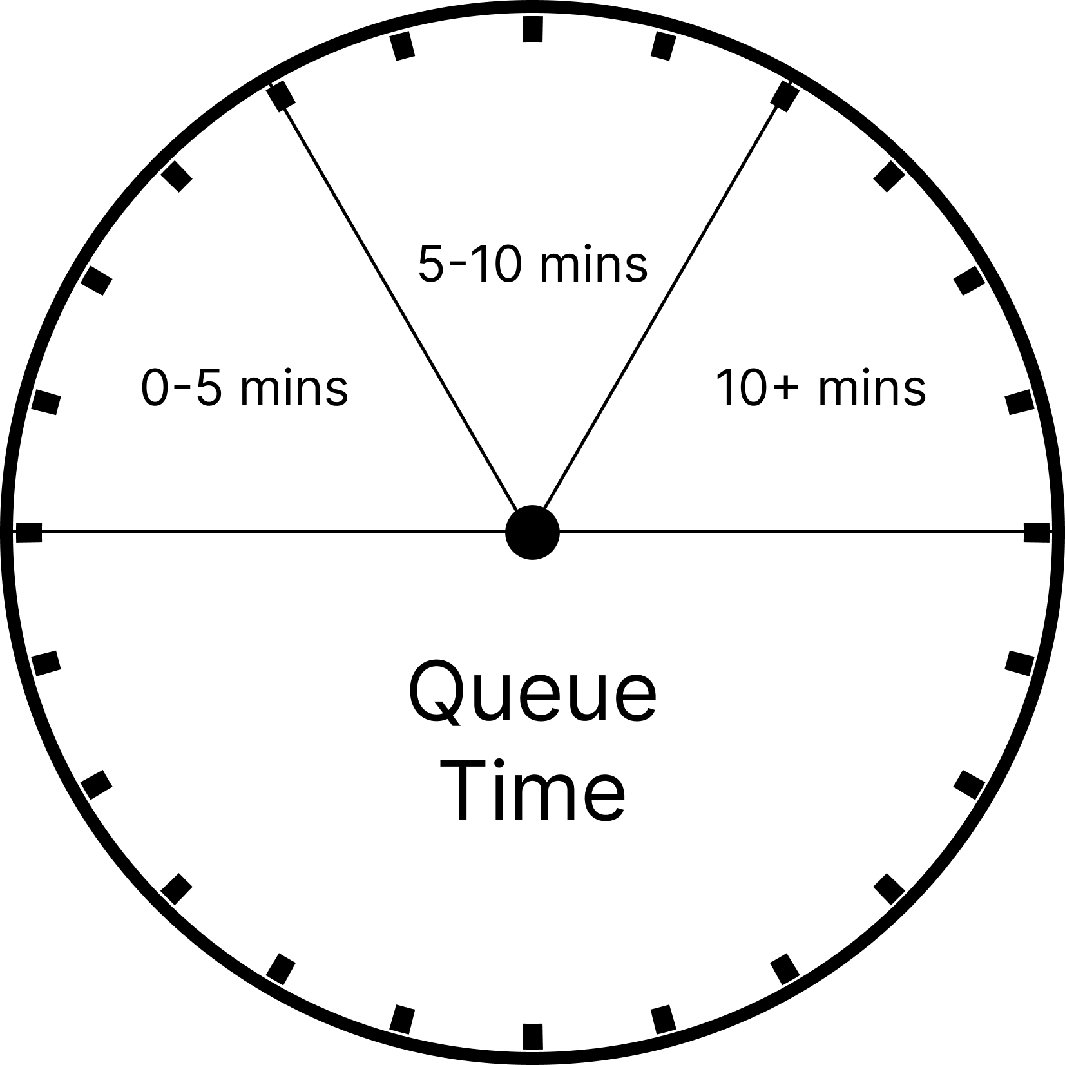
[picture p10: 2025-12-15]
physicalDevice/uvPrint/dialDesignMono-2.png

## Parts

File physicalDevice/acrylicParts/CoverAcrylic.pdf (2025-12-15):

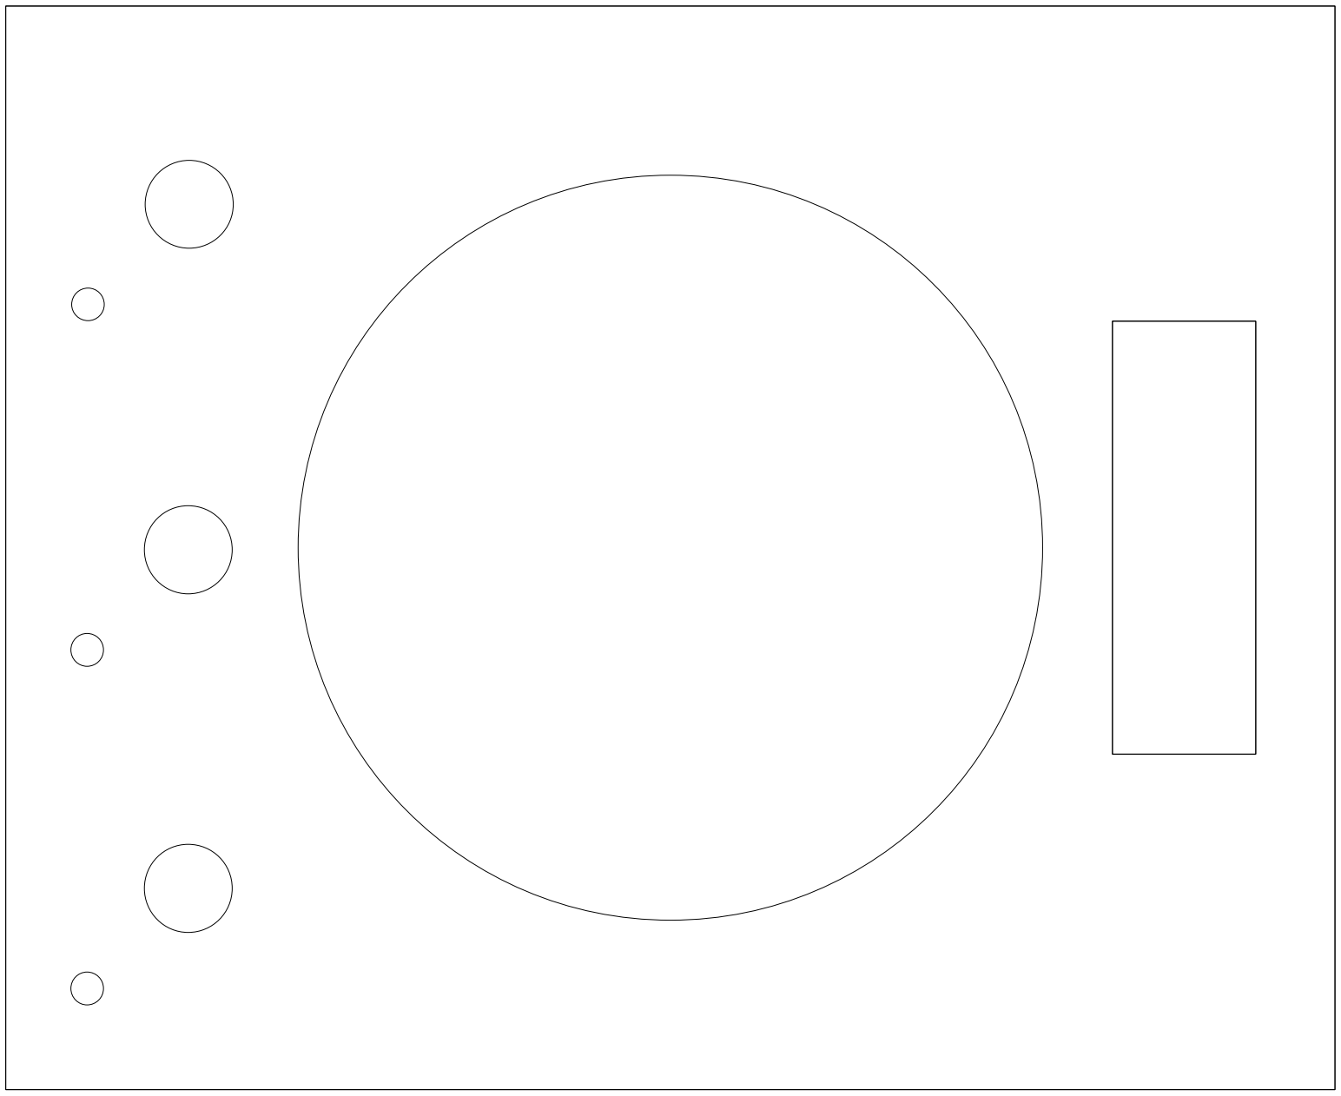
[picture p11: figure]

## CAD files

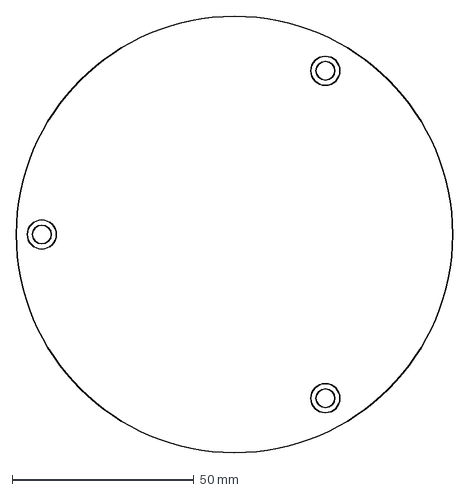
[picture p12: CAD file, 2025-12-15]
physicalDevice/acrylicParts/dial-magnet-cutouts.dxf
120.0 x 120.0 mm

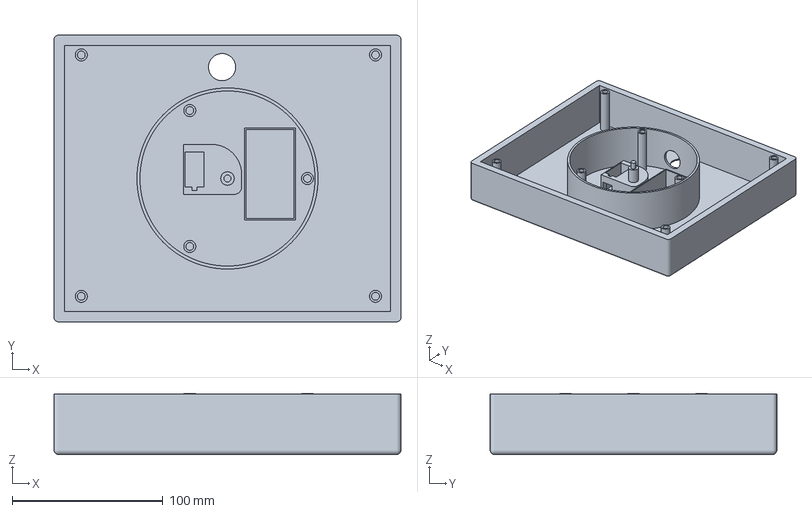
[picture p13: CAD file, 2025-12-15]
physicalDevice/plaParts/3Dprint/basePlate.3mf
230.0 x 190.0 x 40.5 mm

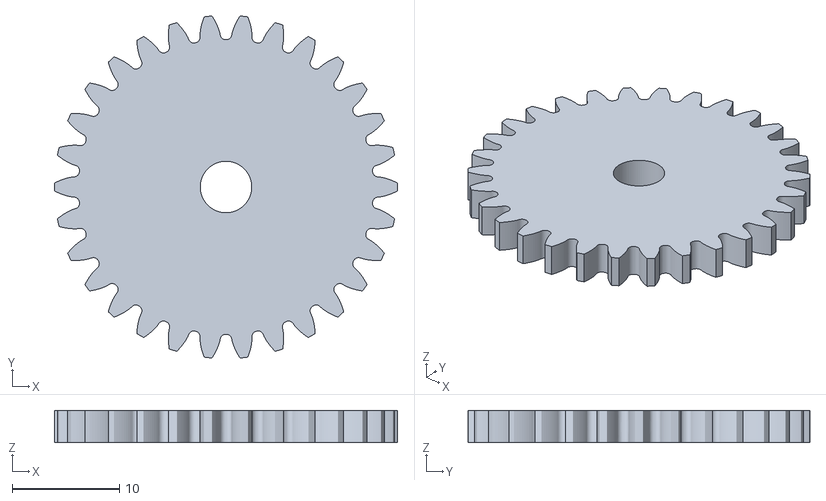
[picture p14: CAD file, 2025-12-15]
physicalDevice/plaParts/Spur Gear (30 teeth).stl
32.0 x 31.9 x 3.00

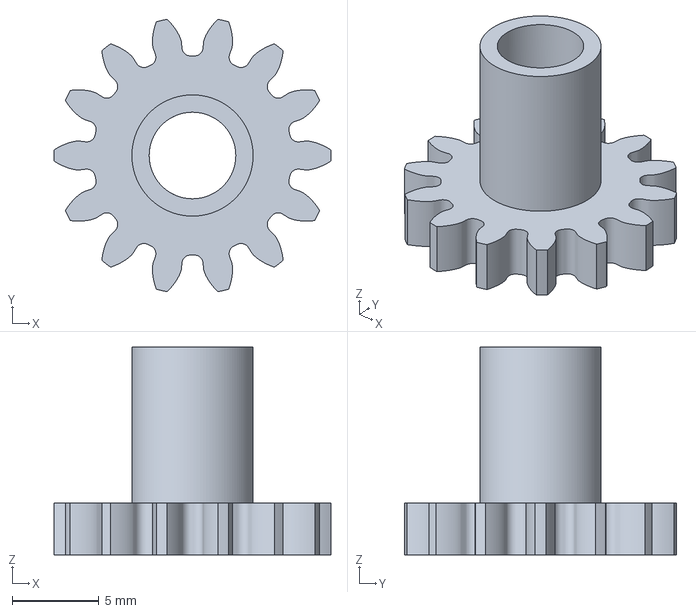
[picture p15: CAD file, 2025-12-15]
physicalDevice/plaParts/unfinished/3Dprint/tall14gear.3mf
16.0 x 15.7 x 12.0 mm

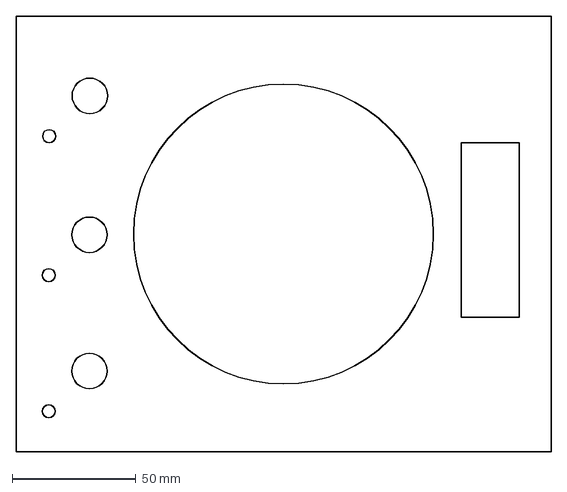
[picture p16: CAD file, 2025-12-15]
physicalDevice/acrylicParts/CoverAcrylic.dxf
216.0 x 176.0 mm

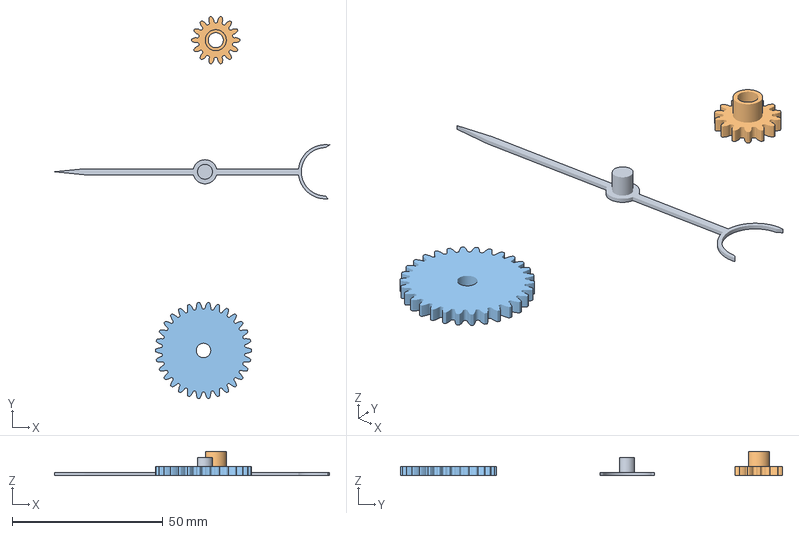
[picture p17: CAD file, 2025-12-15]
physicalDevice/plaParts/3Dprint/Pointer-and-Gears.3mf
91.4 x 126.8 x 8.00 mm
Pointer.stl
Spur Gear (14 teeth).stl
Spur Gear (30 teeth).stl

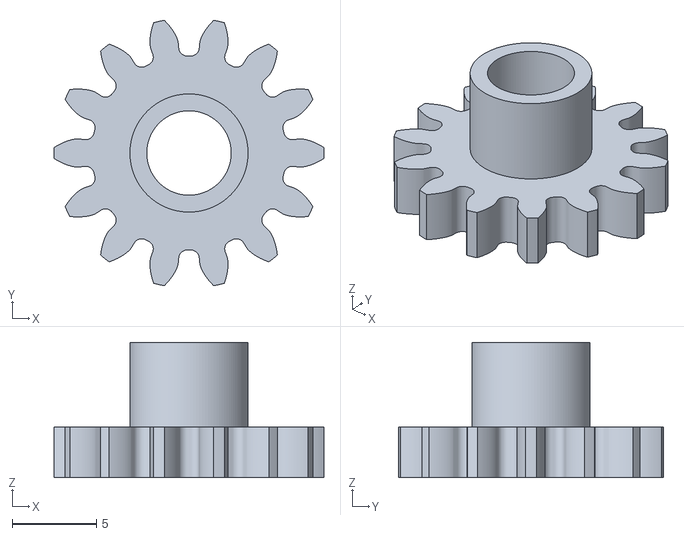
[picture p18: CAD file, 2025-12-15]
physicalDevice/plaParts/Spur Gear (14 teeth).stl
16.0 x 15.7 x 8.00

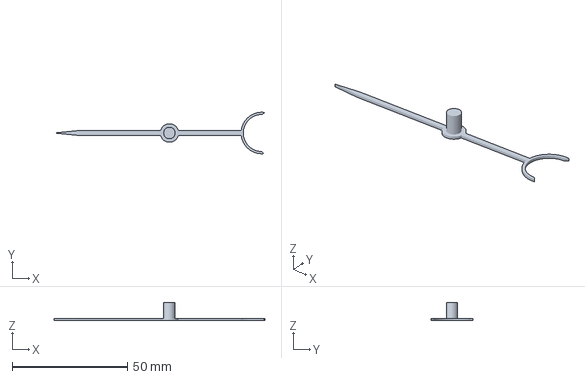
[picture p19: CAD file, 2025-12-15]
physicalDevice/plaParts/unfinished/3Dprint/PointerLarge.3mf
91.4 x 18.0 x 8.00 mm

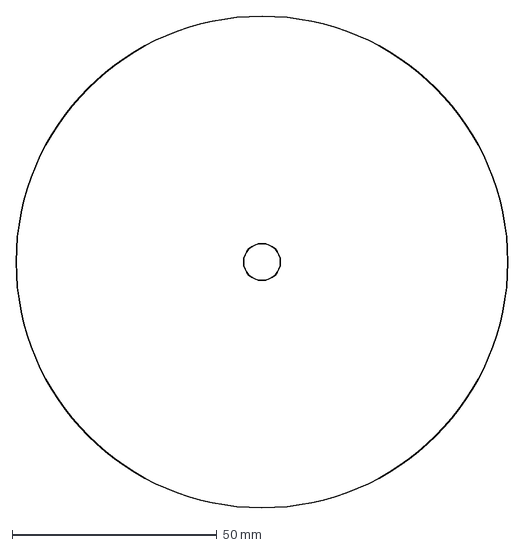
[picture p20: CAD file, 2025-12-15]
physicalDevice/acrylicParts/dial-outline.dxf
120.0 x 120.0 mm

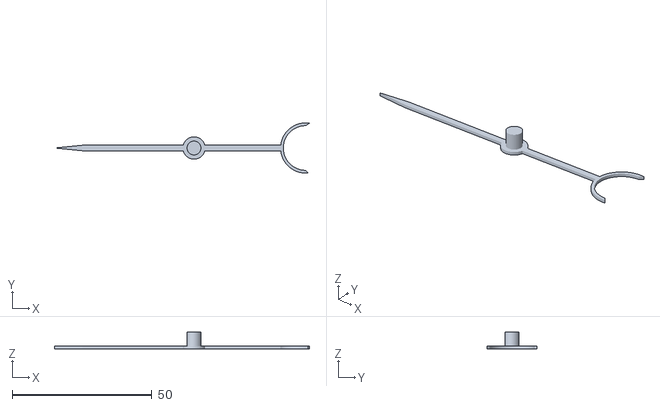
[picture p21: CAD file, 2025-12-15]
physicalDevice/plaParts/Pointer.stl
91.4 x 18.0 x 6.00

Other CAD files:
digitalTwin/models/gauge-digitalTwin.blend
physicalDevice/plaParts/basePlate.stl
physicalDevice/plaParts/gauge.f3d
physicalDevice/plaParts/unfinished/PointerLarge.stl
physicalDevice/plaParts/unfinished/tall14gear.stl

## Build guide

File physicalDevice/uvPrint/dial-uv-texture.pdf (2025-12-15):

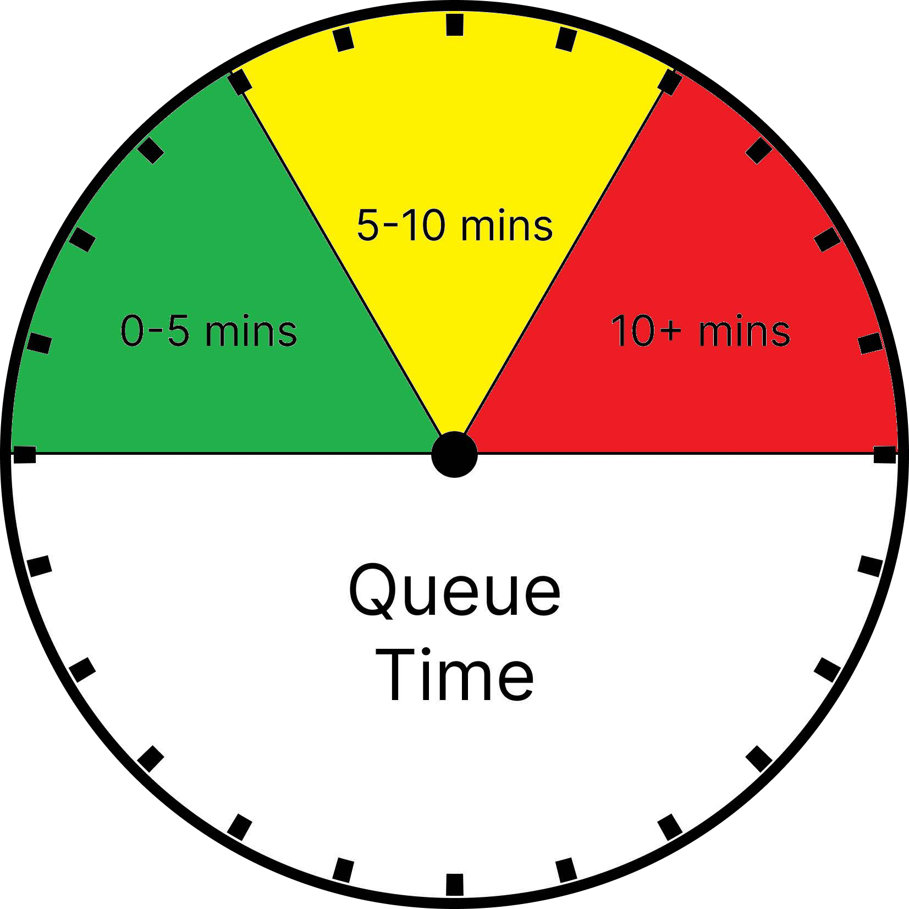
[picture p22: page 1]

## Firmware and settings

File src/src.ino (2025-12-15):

// NodeMCU code for UCL East Food Gauge: "Gauge N'Grab"

#include <ServoEasing.hpp>
#include <WiFiClient.h>
#include <ESP8266WiFi.h>
#include <PubSubClient.h>
#include <NTPClient.h>
#include <WiFiUdp.h>
#include <Wire.h> 
#include <LiquidCrystal_I2C.h>
#include <ArduinoJson.h> 
#include "arduino_secrets.h"

// 180 degree servo, an SG90MG is recomended. 
ServoEasing servo;

// set up LCD display properties
LiquidCrystal_I2C lcd(0x3F, 16, 2); // 16 characters, 2 lines

// setup angle for MG90S
int angle;

// setup LED pins
#define OPScafe_led D5
#define MSGcafe_led D6
#define MSGref_led D7

const int buttonPin1 = D0;  // the number of the pushbutton pin
const int buttonPin2 = D1; 
const int buttonPin3 = D8; 

// set up MQTT topic selection arrays
const char* mqttTopics[] = {
  "student/CASA0019/gauge&grab/pool_street",
  "student/CASA0019/gauge&grab/marshgate_cafe",
  "student/CASA0019/gauge&grab/marshgate_canteen"
};

// Calculate the number of topics automatically
const int topicCount = sizeof(mqttTopics) / sizeof(mqttTopics[0]);
int roomSelIndex = 0; //controls what topic is subscribed and LEDs lit

// connect to wifi and mqtt server
const char* ssid = SECRET_SSID;
const char* password =  SECRET_PASS;
const char* mqttServer = "mqtt.cetools.org"; 
const int mqttPort = 1883;

WiFiClient gaugeNgrab;
PubSubClient client(gaugeNgrab);

void setup()
{
  Serial.begin(9600);

  //initialise LCD display
  Wire.begin(D2, D3); 
  lcd.init();
  lcd.backlight();

  //initialise buttons as inputs
  pinMode(buttonPin1, INPUT); //OPS cafe
  pinMode(buttonPin2, INPUT); //Marshgate cafe
  pinMode(buttonPin3, INPUT); //Marshgate refectory

  pinMode(OPScafe_led, OUTPUT);
  pinMode(MSGcafe_led, OUTPUT);
  pinMode(MSGref_led, OUTPUT);

  //turn on all LEDs at startup
  digitalWrite(OPScafe_led, HIGH);
  digitalWrite(MSGcafe_led, HIGH);
  digitalWrite(MSGref_led, HIGH);

  //Notify user of servo calibration
  lcd.setCursor(0,0); 
  lcd.print("Calibrating");
  lcd.setCursor(0,1); 
  lcd.print("servo...");

  //MQTT connection code
  WiFi.mode(WIFI_STA);
  WiFi.softAPdisconnect(true);

  servo.write(3); 
  servo.attach(D4);

  // Servo Sweep - Useful for Calibration
  servo.setEasingType(EASE_LINEAR);
  servo.setSpeed(15);
  Serial.print("Moving to 0");
  servo.easeTo(10);
  
  delay (1000);
  Serial.print("Moving to 180");
  servo.easeTo(105); 
 
  delay (1000);
  
  Serial.print("Moving to 0");
  servo.easeTo(10);  
 
  Serial.print("Pausing for 5 seconds");
  delay (5000);

  //Notify user that MQTT connection is in progress
  lcd.setCursor(0,0); 
  lcd.clear();          
  lcd.print("Connecting");
  lcd.setCursor(0,1); 
  lcd.print("via MQTT...");

  WiFi.mode(WIFI_STA);
  WiFi.softAPdisconnect(true);
  
  WiFi.setSleepMode(WIFI_NONE_SLEEP);
  
  WiFi.begin(ssid, password);
  while (WiFi.status() != WL_CONNECTED) {
    delay(500);
    Serial.println("Connecting to WiFi..");
  }
  Serial.println("Connected to the WiFi network");
  client.setServer(mqttServer, mqttPort);
  
  client.setCallback(callback);
  while (!client.connected()) {
    Serial.println("Connecting to MQTT...");
    if(client.connect("gaugeNgrab")) {
      Serial.println("connected");
    } else {
      Serial.print("failed state ");
      Serial.print(client.state());
      delay(2000);
    }
  }
 
  client.subscribe(mqttTopics[roomSelIndex]);
  //set LEDs to index 0 configuration (OPS Cafe)
  digitalWrite(OPScafe_led, HIGH);
  digitalWrite(MSGcafe_led, LOW); 
  digitalWrite(MSGref_led, LOW); 
  // Tell user what meal of the day is for OPS (to initialise)
  lcd.clear();           
  lcd.setCursor(0,0); 
  lcd.print("Meal of the day:");
  lcd.setCursor(0,1); 
  lcd.print("Chicken: 3.95");
}

void reconnect() {
  while (!client.connected()) {
    Serial.print("Attempting MQTT connection...");
    String clientId = "ESP8266Client-";
    clientId += String(random(0xffff), HEX);
    if (client.connect(clientId.c_str())) {
      Serial.println("connected");
      client.subscribe(mqttTopics[roomSelIndex]);
    } else {
      Serial.print("failed, rc=");
      Serial.print(client.state());
      Serial.println(" try again in 5 seconds");
      delay(5000);
    }
  }
}

void changeTopic(int newIndex) {
  client.unsubscribe(mqttTopics[roomSelIndex]);
  Serial.print("Unsubscribed from: ");
  Serial.println(mqttTopics[roomSelIndex]);

  roomSelIndex = newIndex;

  client.subscribe(mqttTopics[roomSelIndex]);
  Serial.print("Subscribed to: ");
  Serial.println(mqttTopics[roomSelIndex]);
}

// ---------------------------------------------------------
// UPDATED CALLBACK FUNCTION FOR JSON PARSING
// ---------------------------------------------------------
void callback(const char* topic, byte* payload, unsigned int length) {
  
  Serial.print("Message arrived [");
  Serial.print(topic);
  Serial.print("] ");
  // Print payload for debugging
  for (unsigned int i = 0; i < length; i++) {
    Serial.print((char)payload[i]);
  }
  Serial.println();

  // 1. Allocate a JSON Document
  // 512 bytes is plenty for your object (~150 bytes)
  // If you are using ArduinoJson v7, you can use JsonDocument doc;
  // If using v6, use StaticJsonDocument<512> doc;
  JsonDocument doc; 

  // 2. Deserialize the JSON from the payload
  DeserializationError error = deserializeJson(doc, payload, length);

  // 3. Check for parsing errors
  if (error) {
    Serial.print(F("deserializeJson() failed: "));
    Serial.println(error.f_str());
    return; // Exit if the message isn't valid JSON
  }

  // 4. Extract queue_time_min
  // We check if the key exists to avoid errors if a different message type is sent
  if(!doc.containsKey("queue_time_min")) {
     Serial.println("JSON does not contain 'queue_time_min'");
     return;
  }

  int qt = doc["queue_time_min"];

  // ---------------------------------------------------------
  // ORIGINAL LOGIC
  // ---------------------------------------------------------

  int queueTime = constrain(qt, 0, 20); //failsafe to prevent pointer going past 180deg
  
  // Edit the range to match your own servo configeration  
  angle = map(queueTime, 0, 20, 10, 105);   // Edit Values to Match Your Data Values and Servo Range
 
  // Calculate the difference in angle
  int angleDifference = abs(servo.read() - angle);

  // Adjust speed and easing type based on the angle difference
  if (angleDifference < 10) {
    servo.setSpeed(5); // Slower for small changes
    servo.setEasingType(EASE_LINEAR); // Linear easing for smoother small movements
  } else {
    servo.setSpeed(10); // Faster for larger changes
    servo.setEasingType(EASE_CUBIC_IN_OUT); // Cubic easing for larger movements
  }

  // Move servo to the new position
  servo.easeTo(angle);
  Serial.print("Queue Time: ");
  Serial.println(queueTime);
  delay(500); // Allow transit time
}

void loop() {
    if (!client.connected()) {
      reconnect();
    }
    client.loop();
  
  // read the state of the pushbutton value:
  if (digitalRead(buttonPin1) == HIGH && roomSelIndex != 0) {
      Serial.println("Button 1 Pressed: Switching to OPS Cafe");
      changeTopic(0);
      digitalWrite(OPScafe_led, HIGH);
      digitalWrite(MSGcafe_led, LOW); 
      digitalWrite(MSGref_led, LOW); 
      delay(200); 
      lcd.clear();           
      lcd.setCursor(0,0); 
      lcd.print("Meal of the day:");
      lcd.setCursor(0,1); 
      lcd.print("Chicken: 3.95");
  }
  else if (digitalRead(buttonPin2) == HIGH && roomSelIndex != 1) {
      Serial.println("Button 2 Pressed: Switching to Marshgate Cafe");
      changeTopic(1);
      digitalWrite(OPScafe_led, LOW);
      digitalWrite(MSGcafe_led, HIGH); 
      digitalWrite(MSGref_led, LOW); 
      delay(200); 
      lcd.clear();           
      lcd.setCursor(0,0); 
      lcd.print("Meal of the day:");
      lcd.setCursor(0,1); 
      lcd.print("Beef: 4.10");
  }
  else if (digitalRead(buttonPin3) == HIGH && roomSelIndex != 2) {
      Serial.println("Button 3 Pressed: Switching to Marshgate Refectory");
      changeTopic(2);
      digitalWrite(OPScafe_led, LOW);
      digitalWrite(MSGcafe_led, LOW); 
      digitalWrite(MSGref_led, HIGH); 
      delay(200);
      lcd.clear();           
      lcd.setCursor(0,0); 
      lcd.print("Meal of the day:");
      lcd.setCursor(0,1); 
      lcd.print("Lamb: 3.55");
    }
}

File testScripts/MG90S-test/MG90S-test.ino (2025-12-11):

// #include <Servo.h> //import library
#include <ServoEasing.hpp> //import library

ServoEasing servo;     //initialise servo object
void setup() {
  Serial.begin(9600);
  servo.attach(D4); //set pin D4 to control servo. REMEMBER: D4 !== 4
  Serial.println("setup complete");
}

void loop() {
  Serial.println("init loop");

  servo.setEasingType(EASE_LINEAR);
  servo.setSpeed(15);
  Serial.print("Moving to 0");
  servo.easeTo(10);
  Serial.println("servo moved to 0 degrees");
  delay(2000);
  servo.easeTo(100);
  Serial.println("servo moved to 90 degrees");
  delay(2000);


  // for (int pos = 0; pos<=180; pos++) { //iterate over 0-180 degrees of servo motion:
  //   myservo.write(pos); //update servo position every degree
  //   delay(15);
  // }
  // Serial.println("servo moved");
  // delay(1000);

  // for (int pos = 180; pos >=0; pos--) {
  //   myservo.write(pos);
  //   delay(15);
  // }
  // Serial.println("servo moved back");
  // delay(1000);
}

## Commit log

2025-12-10 data device website
2025-12-11 fix: update Node main and servo test code
    [MG90S-test.ino]
2025-12-15 feat: create dial decal pdf for uv print
2025-12-15 chore: refactor directory and cleanup unused files
    [CoverAcrylic.dxf, Guage and Grab Final Menu Datasets (3 locations).ods, Pointer-and-Gears.3mf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]
2025-12-16 feat: embed physical device image in readme
2026-01-06 Revise README for DaBo project details
    Updated the README to enhance clarity on device usage, running instructions, limitations, and future development plans for the DaBo project.
2026-01-06 device_template.json with unified data contract
2026-01-11 Revise README for Guage and Grab IOT Device System
    Updated README to enhance project details
